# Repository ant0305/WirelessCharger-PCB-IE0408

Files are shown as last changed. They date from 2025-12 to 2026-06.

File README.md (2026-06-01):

# WirelessCharger-PCB-IE0408
Repositorio para el proyecto final del curso IE0408 sobre el diseño de una PCB de un cargador inalambrico. Contiene el circuito esquemático, el diseño de la PCB en *KiCad* y documentación sobre los componentes a utilizar, el procedimiento de diseño y otros detalles. 

Este repositorio y sus contenidos fueron diseñados durante el curso IE0408 durante el periodo II-2025 por los siguientes integrantes del equipo:

<div align="center">

| **Integrantes** | **Carné** | **Correo electrónico**|
|:---:|:---:|:---:|
| Anthony Calvo García | C11433  |  anthonycalvo50@gmail.com |
| Rodrigo Madrigal Montes | C24458  | rmadrigalmontes@gmail.com |

</div>

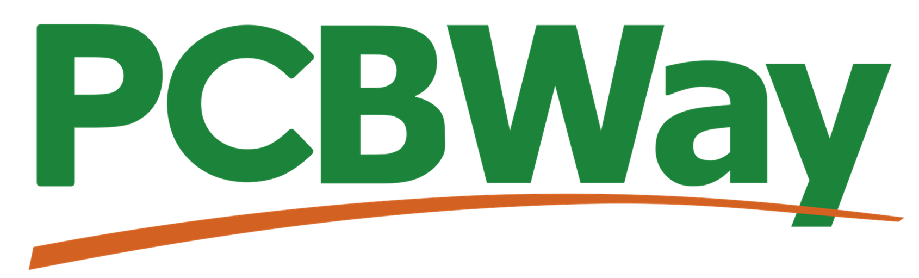
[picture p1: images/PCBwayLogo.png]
PCBWay_Logo
## Agradecimientos a  

El proyecto presentado fue posible gracias al valioso respaldo de **PCBWay**, a quienes deseamos extender nuestro más sincero agradecimiento. Las PCBs entregadas mostraron ser de una excelente calidad durante las pruebas realizadas, además de que el acabado en cada una de ellas es impecable, brindando exactamente el resultado que esperábamos.

Agradecemos, de igual manera, al equipo encargado de la atención al cliente, los cuales están siempre disponibles para brindar el apoyo solicitado de forma rápida y asertiva, lo que nos dio seguridad y tranquilidad durante todo el proceso de elaboración y entrega de las PCBs. 

### PCBs ensambladas 

Una vez recibidas las placas de PCBWay, se procedió con el ensamblaje manual de todos los componentes. A continuación se muestran imágenes del resultado:

<div align="center">

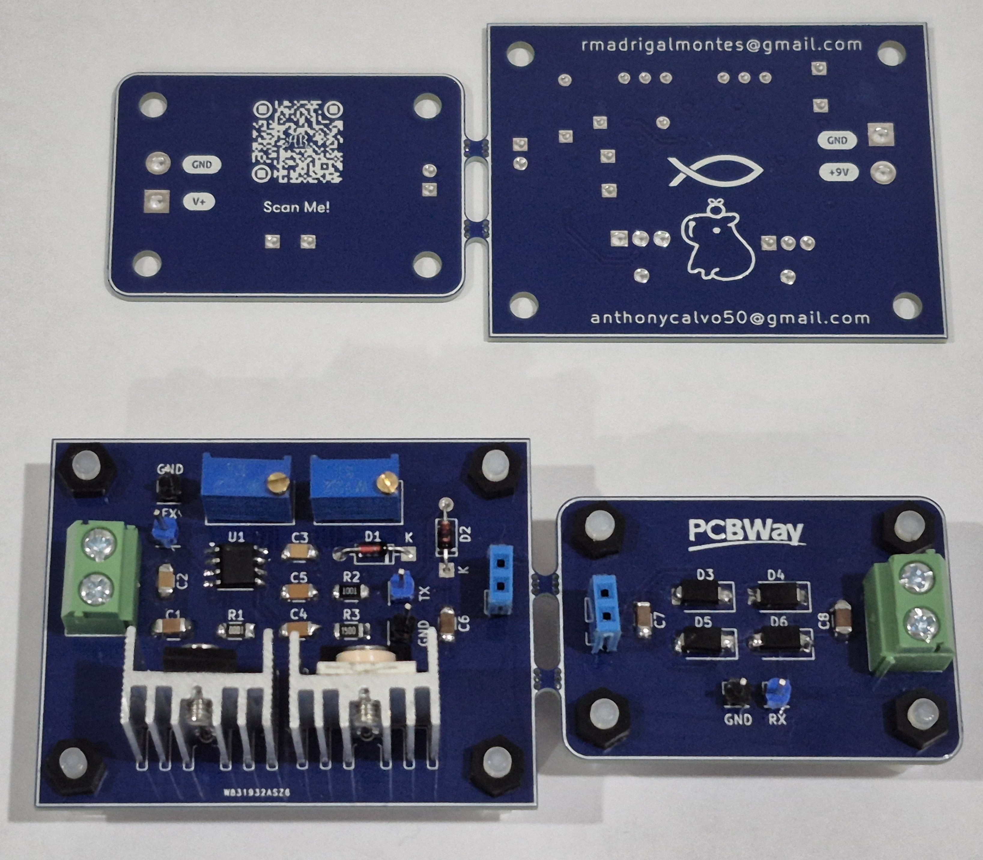
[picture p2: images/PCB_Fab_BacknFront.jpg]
PCBs_Fab_Unidas
|  |
|:-----------------------------:|
|    *PCBs ensambladas y no ensambladas aún unidas*     |

</div>

<div align="center">

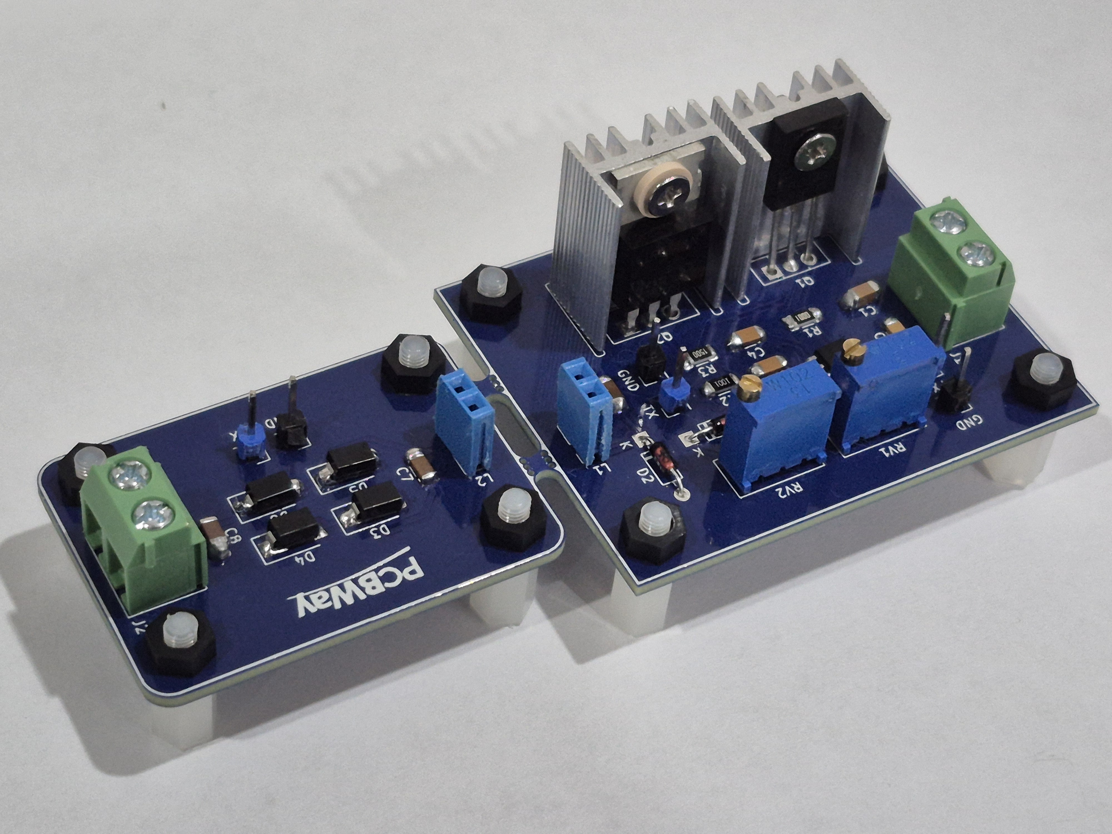
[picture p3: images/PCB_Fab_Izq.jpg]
PCBs_Fab_Izq
|  |
|:-----------------------------:|
|    *Vista lateral de las PCBs ensambladas unidas*     |

</div>

Una vez soldados todos los componentes en ambas PCBs se procedió a separarlas, rompiendo la uniones entre ambas como se muestra a continuación:

<div align="center">

| PCBs_Sep |
|:-----------------------------:|
|    *Separación de ambas PCBs*     |

</div>

Y una vez separadas, lijando el sobrante de la junta de unión en ambas PCBs y agregando las bobinas el resultado final es el siguiente:

<div align="center">

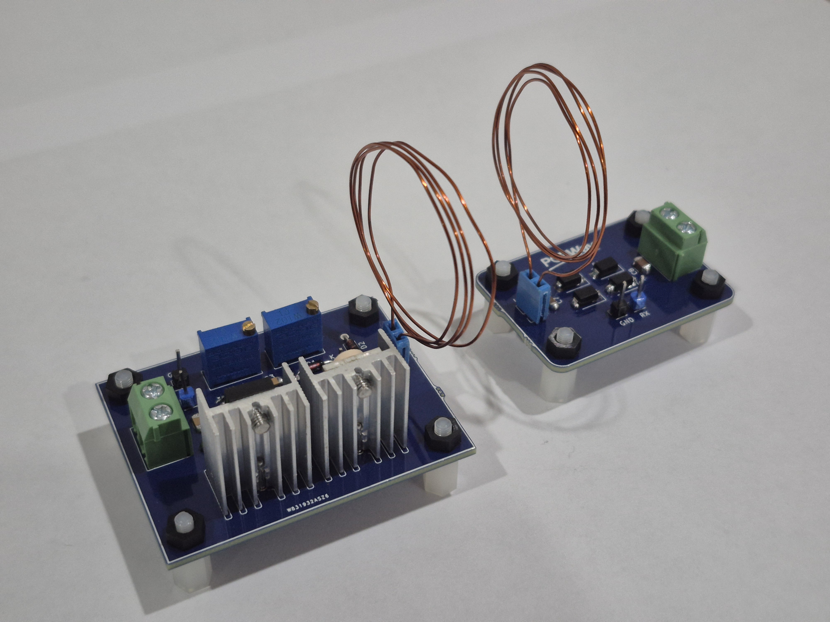
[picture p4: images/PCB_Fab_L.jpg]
PCBs_Fab_L
|  |
|:-----------------------------:|
|    *Ambas PCBs ensambladas y separadas*     |

</div>

Nuevamente extendemos nuestros agradecimientos a **PCBWay** por apoyar a la realización de este proyecto. Recomendamos sus servicios para estudiantes, profesionales y cualquier persona interesada en manufacturar PCBs de alta calidad. Más información en [pcbway.com](https://www.pcbway.com).

### Lista de componentes

A continuación se incluye una lista con los componentes utilizados en el diseño, con el mismo número que se les asignó en el diseño final de PCB:

<div align="center">

| Componente | Valor / Modelo | Descripción / Función | Encapsulado |
|:---:|:---:|:---:|:---:|
| C1, C8 | 10uF, 2.2uF | Capacitor cerámico | (SMD) 1206 |
| C2, C3 | 100nF | Capacitor cerámico | (SMD) 1206 |
| C4, C5 | 10nF | Capacitor cerámico | (SMD) 1206 |
| C6, C7 | 2nF | Capacitor cerámico | (SMD) 1206 |
| D1, D2 | 1N4148 | Diodo Rectificador de alta velocidad | (THT) DO-35 |
| D3, D4, D5, D6 | SS14 | Diodo Schottky | (SMD) DO-214|
| J1, J2 | — | Terminal de tornillo (2 pines) | — | 
| L1, L2 | 1x02 (2.54mm) Female Header | Conectores para colocar las bobinas | — |
| Q1 | BD139 | Transistor NPN de potencia | (THT) TO-126 |
| Q2 | IRFZ44N | Transistor MOSFET de potencia | (THT) TO-220 |
| R1 | 100Ω | Resistor | (SMD) 1206 |
| R3 | 150Ω | Resistor | (SMD) 1206 |
| R2| 1kΩ | Resistor | (SMD) 1206 |
| RV1, RV2 | 1kΩ | Resistor variable/Potenciómetro, | (THT) 3296W |
| U1 | NE555D | Circuito Integrado Temporizador NE555 | (SMD) SOP8 |
| TP1, TP3, TP6 | 1x01 (2.54mm) Pin Header | Punto de prueba (Test Point) para Tierra (GND) | — |
| TP2 | 1x01 (2.54mm) Pin Header | Punto de prueba (Test Point) para medir la Salida del NE555 | — | 
| TP4 | 1x01 (2.54mm) Pin Header | Punto de prueba (Test Point) para medir la tensión del Receptor (RX) | — |
| TP5 | 1x01 (2.54mm) Pin Header | Punto de prueba (Test Point) para medir la tensión del Receptor (TX) | — | 

</div>

## Diseño de la PCB

Una vez simulado y definido el circuito final, se diseñó la PCB en *KiCad* con una arquitectura de **cuatro capas**, las cuales se distribuyen de la siguiente manera:

- **F.Cu**: Ruta de señales
- **In1.Cu**: Plano de alimentación +9V
- **In2.Cu**: Plano de tierra (GND)
- **B.Cu**: Ruta de señales

### Capas de la PCB

<div align="center">

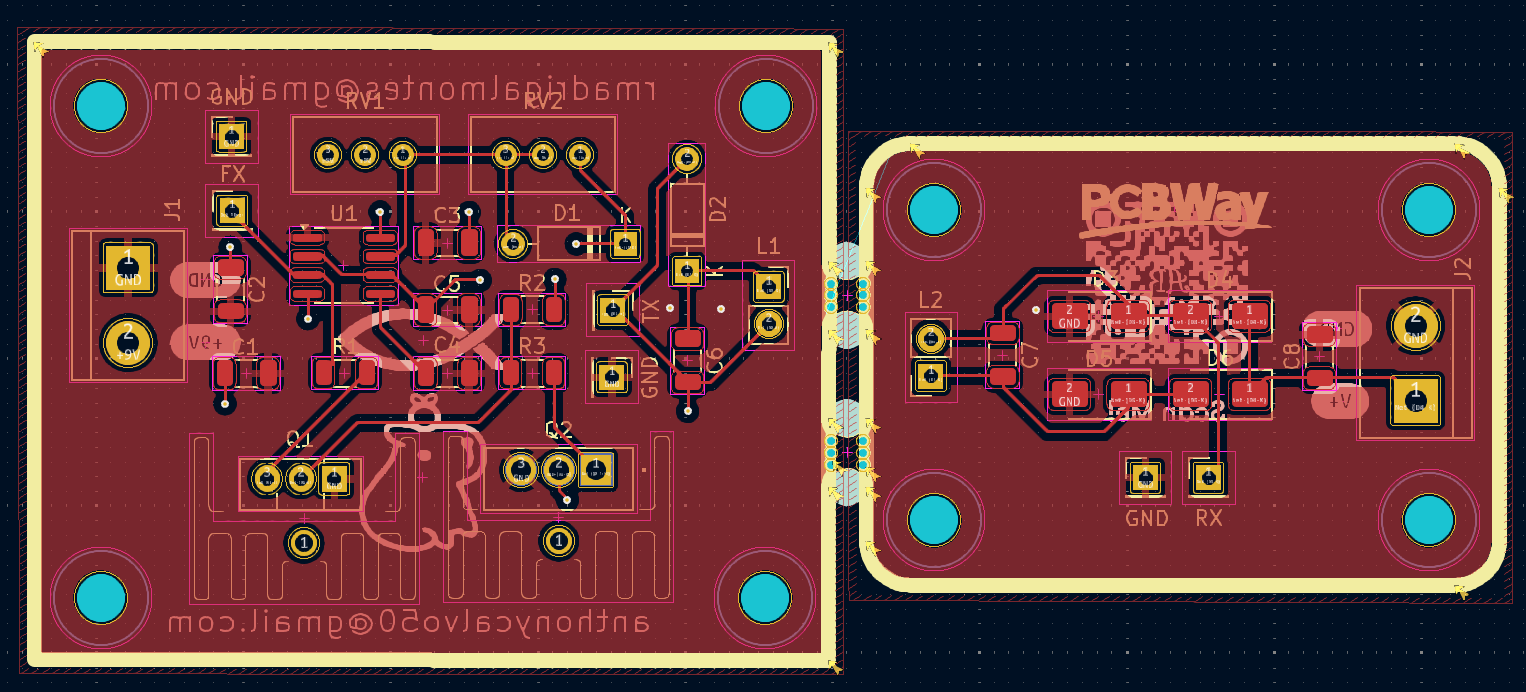
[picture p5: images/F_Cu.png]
Capa F.Cu
|  |
|:-----------------------------:|
|    *Capa superior (F.Cu)*     |

</div>

<div align="center">

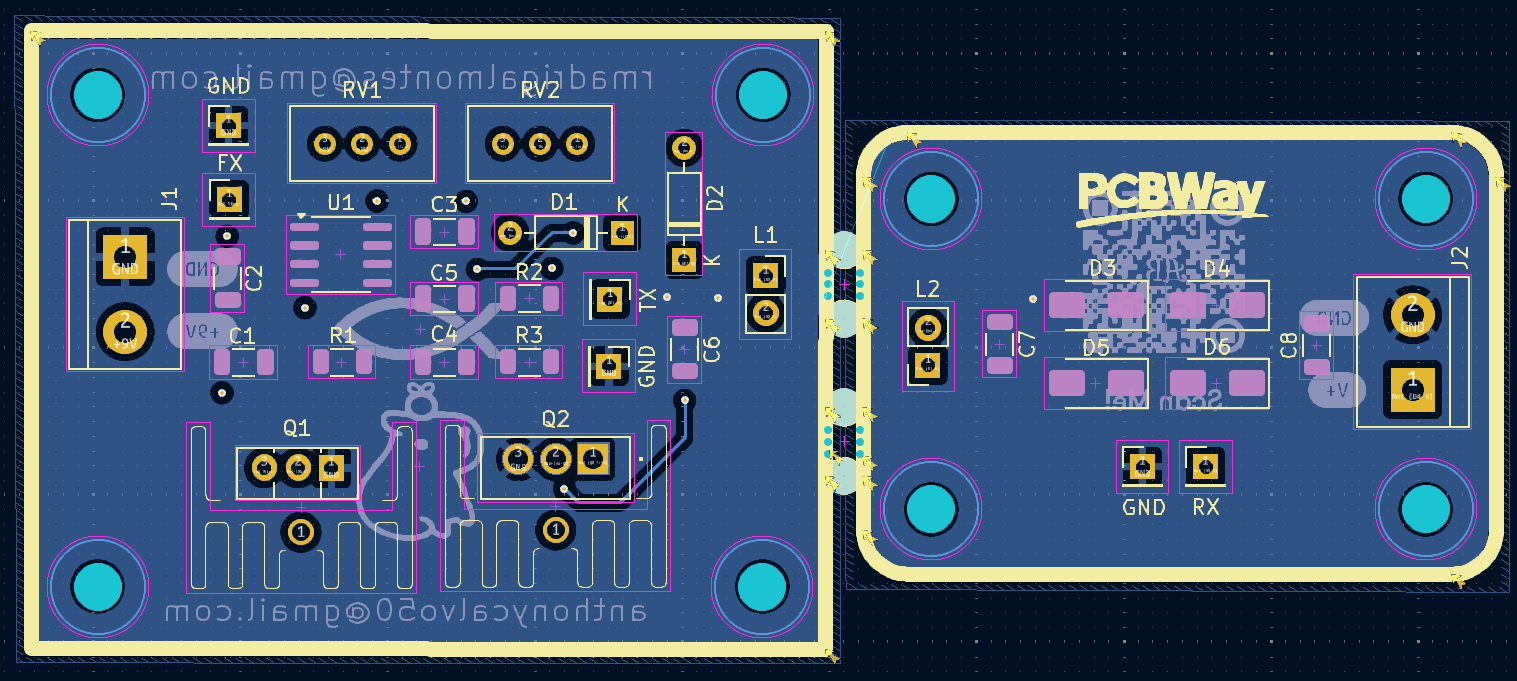
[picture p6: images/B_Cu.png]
Capa B.Cu
|  |
|:-----------------------------:|
|    *Capa inferior (B.Cu)*     |

</div>

<div align="center">

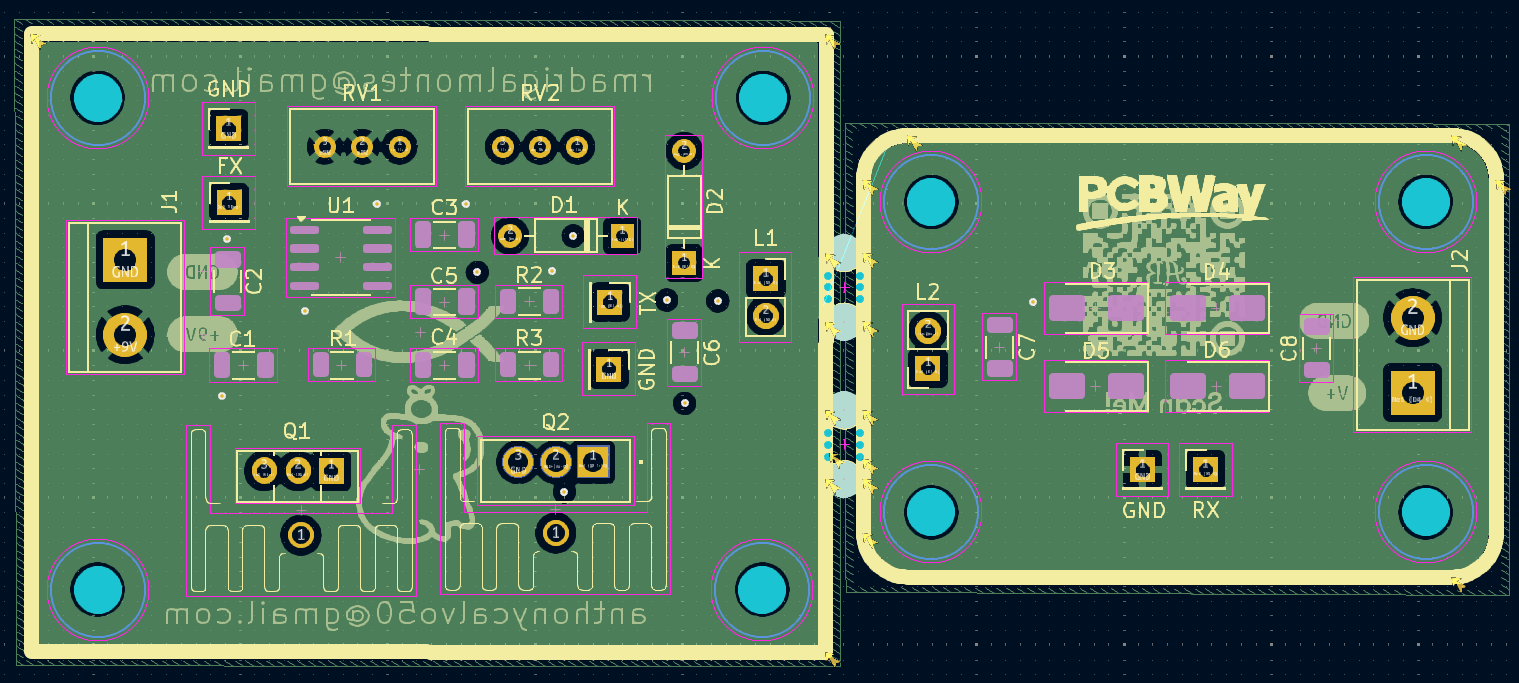
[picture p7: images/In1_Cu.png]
In1.Cu - Alimentación
|  |
|:-------------------------------------------:|
|      *Capa interna 1 (In1.Cu)- +9V*         |

</div>

<div align="center">

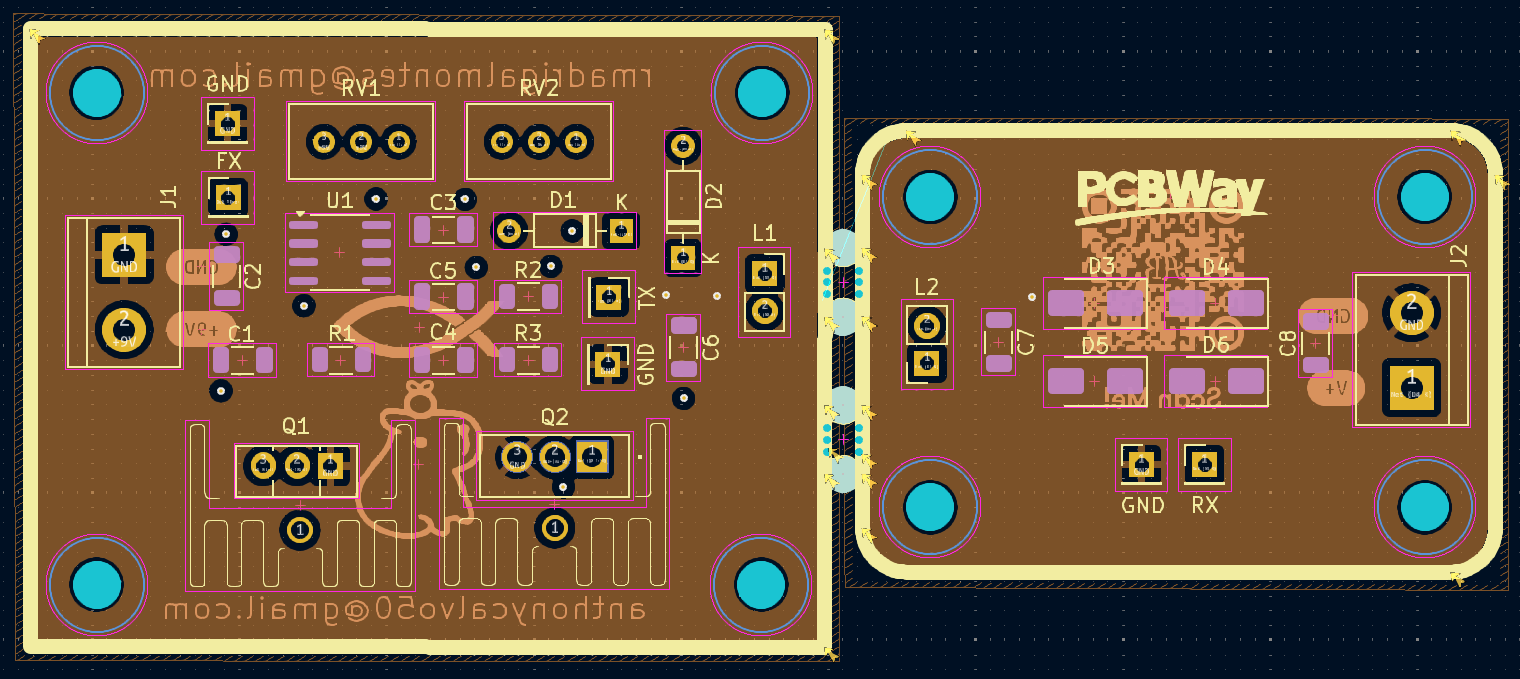
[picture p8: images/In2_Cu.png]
In2.Cu - Tierra
|  |
|:-------------------------------------:|
|        *Capa interna (In2.Cu) - GND*         |

</div>

Además, se agregaron zonas de serigrafía, agujeros de montaje, así como textos identificativos y logotipos en el *silkscreen* con el nombre del proyecto y los autores. Como resultado final se muestra la PCB en el visor 3D de *KiCad* con y sin los modelos 3D 

<div align="center">

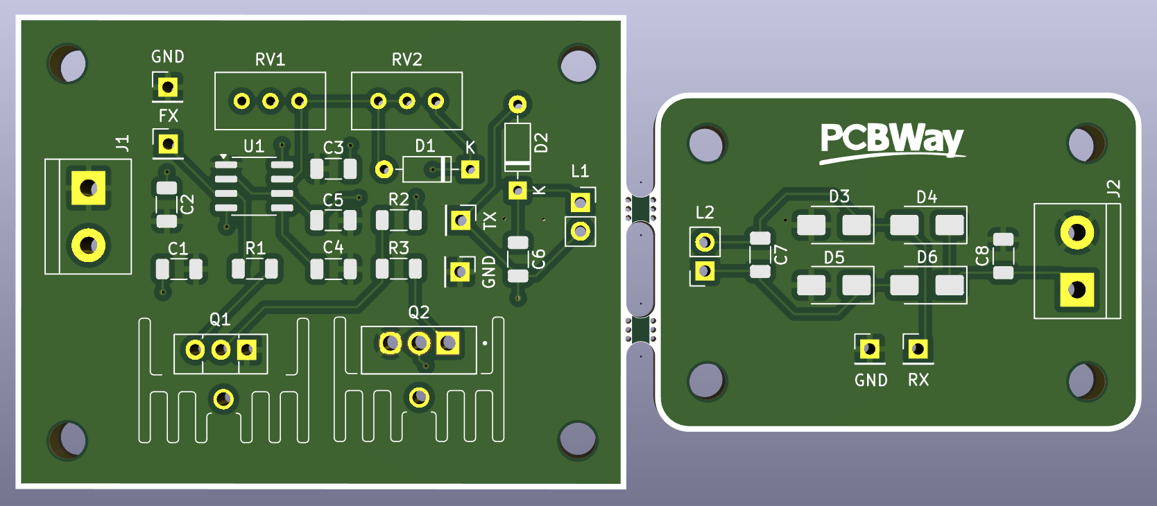
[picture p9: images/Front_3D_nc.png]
|  |
|:--:|
| *Vista 3D Frontal de la PCB en KiCad* |

</div>

<div align="center">

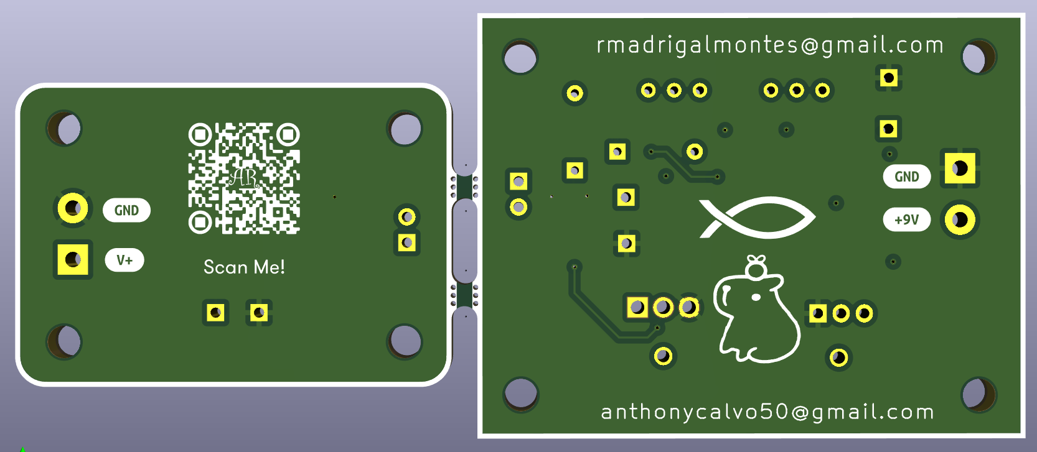
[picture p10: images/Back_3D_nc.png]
|  |
|:--:|
| *Vista 3D Frontal de la PCB en KiCad* |

</div>

<div align="center">

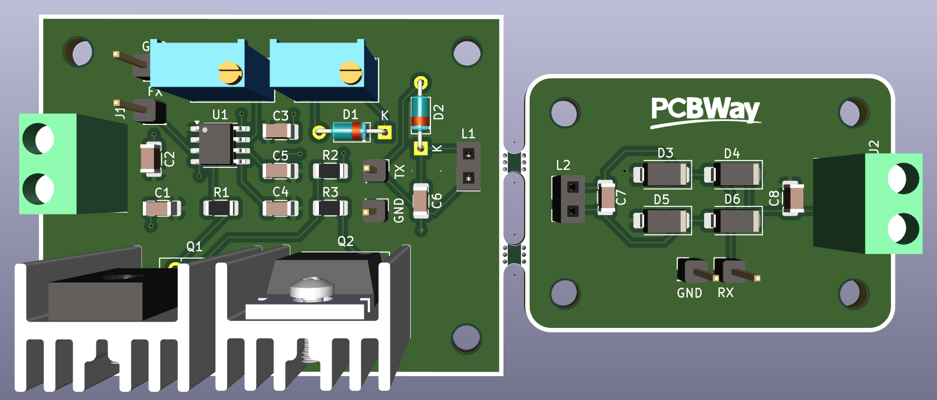
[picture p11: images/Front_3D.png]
Vista 3D Frontal de la PCB con Modelos
|  |
|:--:|
| *Vista 3D Frontal de la PCB en KiCad con modelos 3D* |

</div>

<div align="center">

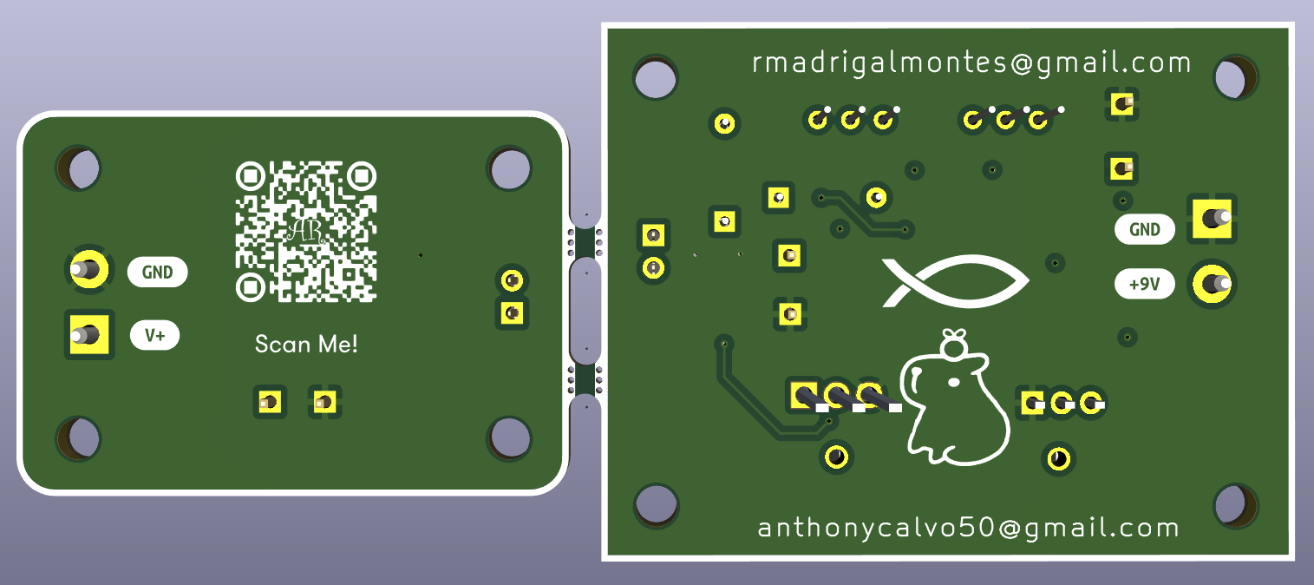
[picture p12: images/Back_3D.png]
Vista 3D Trasera de la PCB con Modelos
|  |
|:--:|
| *Vista 3D Trasera de la PCB en KiCad con modelos 3D* |

</div>

<div align="center">

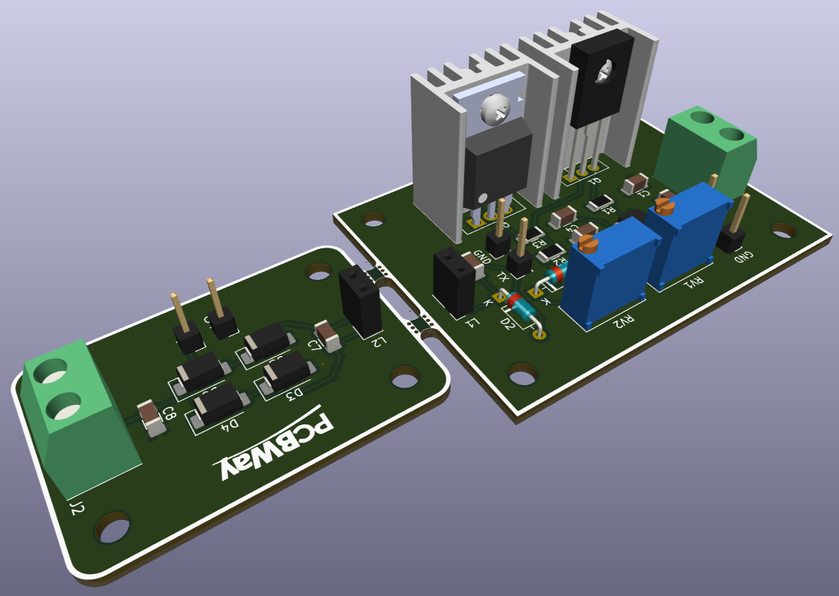
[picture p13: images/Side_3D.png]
Vista 3D Lateral Izquierda de la PCB con 3D
|  |
|:--:|
| *Vista 3D Lateral Izquierda de la PCB en KiCad con modelos 3D* |

</div>

## Diseño de una carcasa 3D

De forma adicional, se diseñó una carcasa 3D usando la herramienta FreeCAD que permite comprobar el correcto funcionamiento del prototipo y cómo cambia la cantidad de energía entregada dependiendo de la distancia entre el receptor y el emisor.

<div align="center">

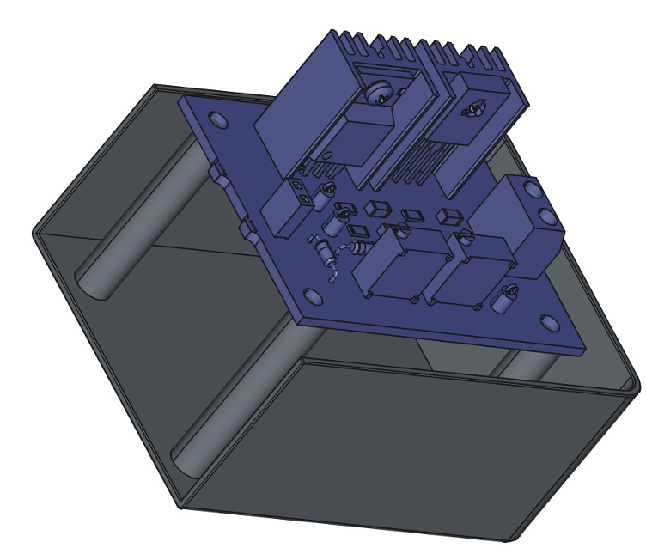
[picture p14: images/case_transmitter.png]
Vista 3D de la carcasa del emisor
|  |
|:--:|
| *Vista 3D de la carcasa diseñada para el emisor* |

</div>

<div align="center">

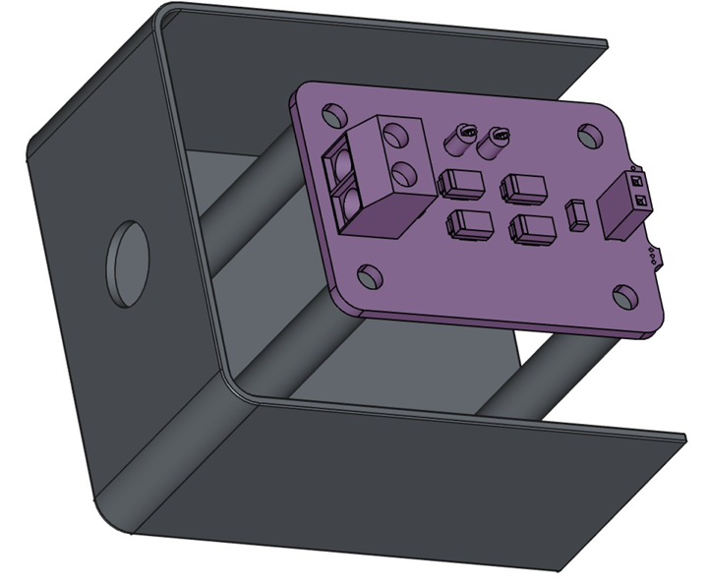
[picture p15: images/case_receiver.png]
Vista 3D de la carcasa del receptor
|  |
|:--:|
| *Vista 3D de la carcasa diseñada para el receptor* |

</div>

<div align="center">

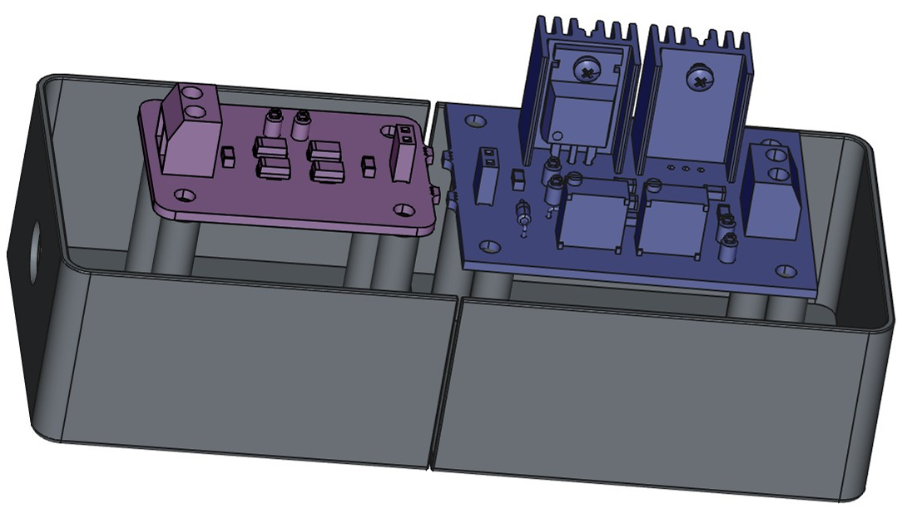
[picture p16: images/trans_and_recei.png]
Vista 3D de la carcasa del receptor y emisor
|  |
|:--:|
| *Unión del emisor y receptor usando la carcasa diseñada* |

</div>

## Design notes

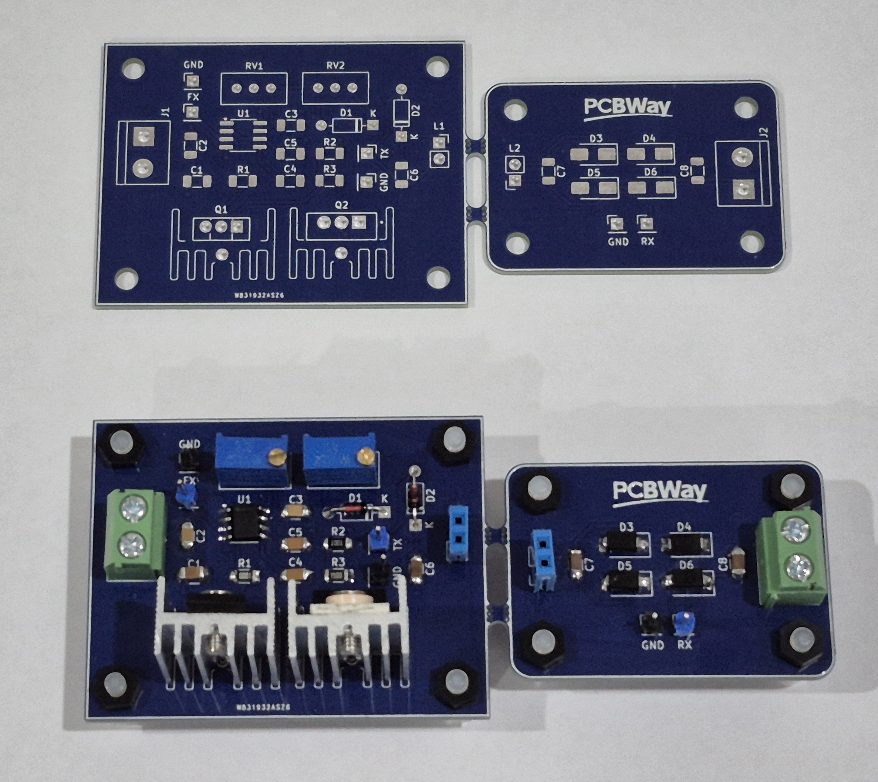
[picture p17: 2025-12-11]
images/PCB_F_NF.jpg

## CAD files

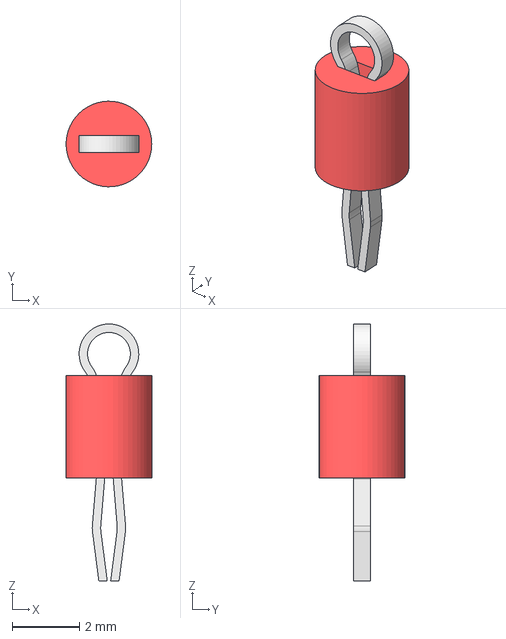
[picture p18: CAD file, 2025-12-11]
kicad_project/3Dmodels/TP_RED_1.0mm_miniature.stp
2.54 x 2.54 x 7.62 mm

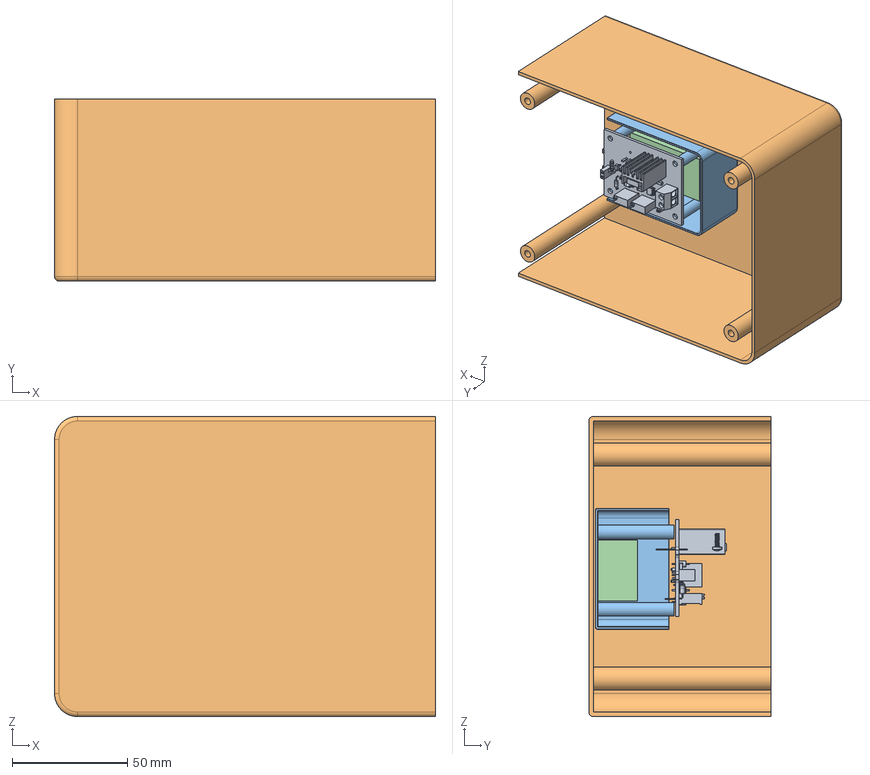
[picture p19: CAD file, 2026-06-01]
kicad_project/Freecad_case/emisor.FCStd
165.0 x 79.0 x 130.0 mm
Cuerpo
Caja

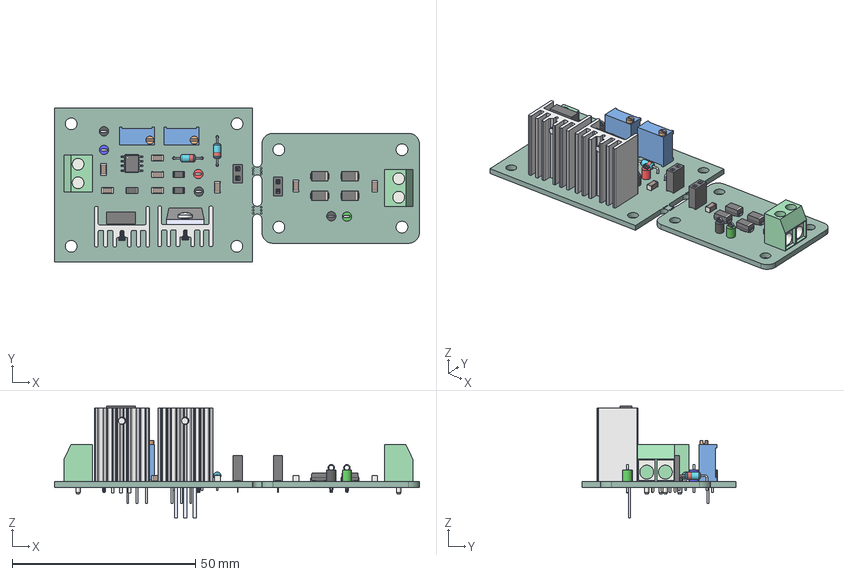
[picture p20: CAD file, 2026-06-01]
kicad_project/WirelessChargerPCB.step
99.5 x 42.0 x 30.5 mm
TerminalBlock_bornier-2_P5.08mm x 2
PinSocket_1x02_P254mm_Vertical x 2
R_1206_3216Metric x 3
C_1206_3216Metric x 8
D_DO-35_SOD27_P7.62mm_Horizontal x 2
D_SMA x 4
SOIC_8_39x49mm_P127mm
IRFZ44N
ASSEMBLY x 2
Potentiometer_Bourns_3296W_Vertical x 2
TO-126-3_Vertical
WirelessChargerPCB_PCB

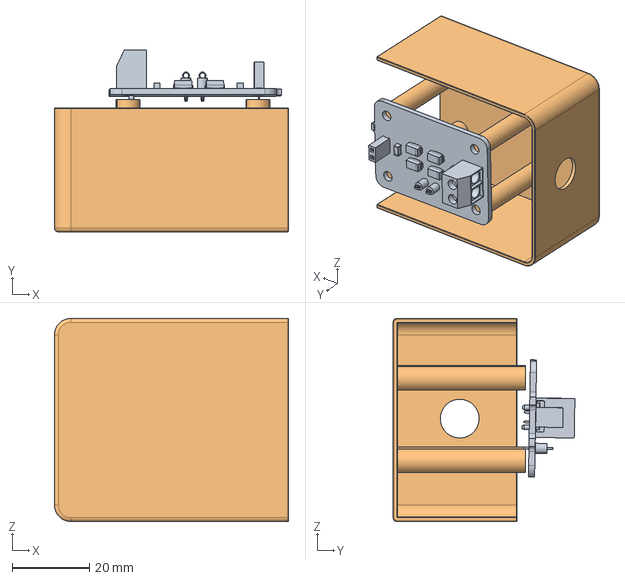
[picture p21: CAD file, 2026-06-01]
kicad_project/Freecad_case/receptor.FCStd
60.4 x 46.9 x 52.4 mm
Slice003.0

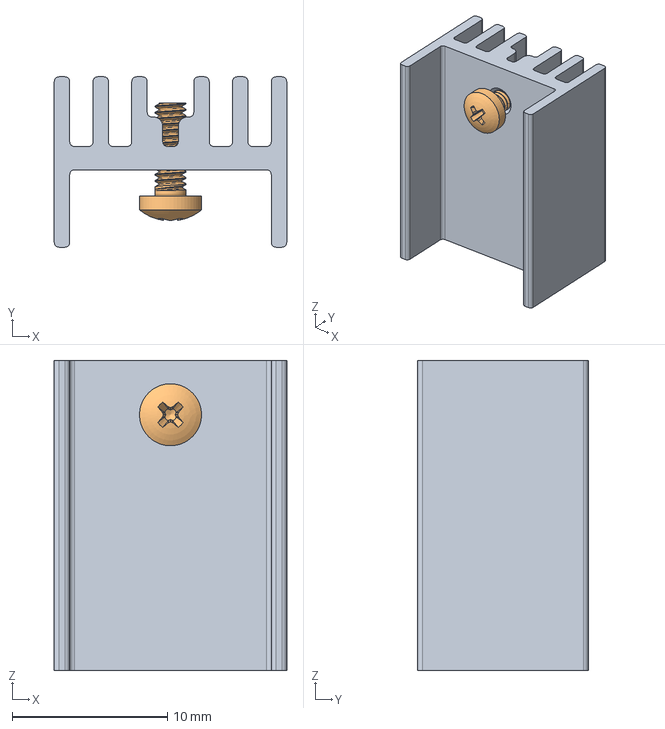
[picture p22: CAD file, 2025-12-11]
kicad_project/3Dmodels/HeatsinkTO220.step
15.0 x 11.0 x 20.0 mm
HeatSink
M2x6-Screw

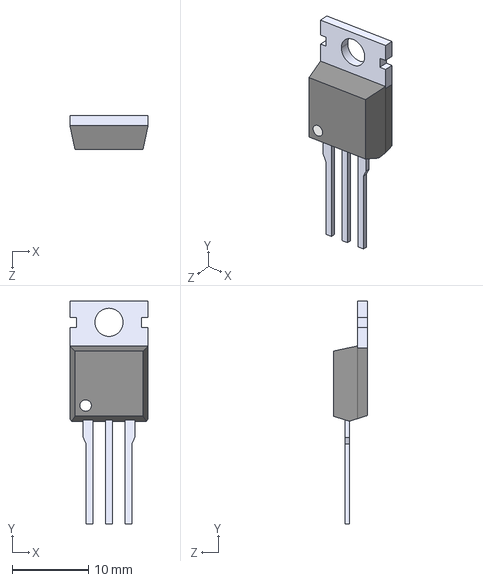
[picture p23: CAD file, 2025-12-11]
kicad_project/3Dmodels/IRFZ44N.step
10.3 x 29.3 x 4.50 mm

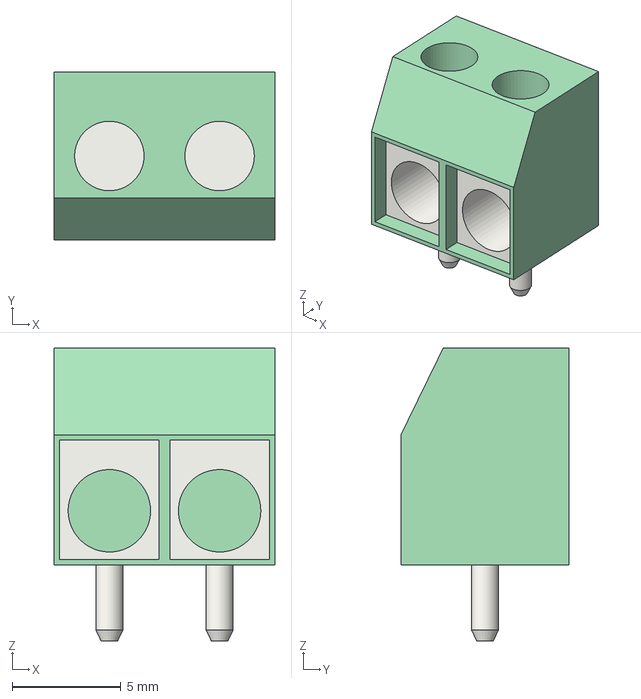
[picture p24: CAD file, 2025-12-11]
kicad_project/3Dmodels/TerminalBlock_bornier-2_P5.08mm.step
10.2 x 7.75 x 13.5 mm

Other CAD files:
kicad_project/3Dmodels/TP_GREEN_1.0mm_miniature.stp
kicad_project/3Dmodels/TP_BLACK_1.0mm_miniature.stp
kicad_project/3Dmodels/TP_BLUE_1.0mm_miniature.stp

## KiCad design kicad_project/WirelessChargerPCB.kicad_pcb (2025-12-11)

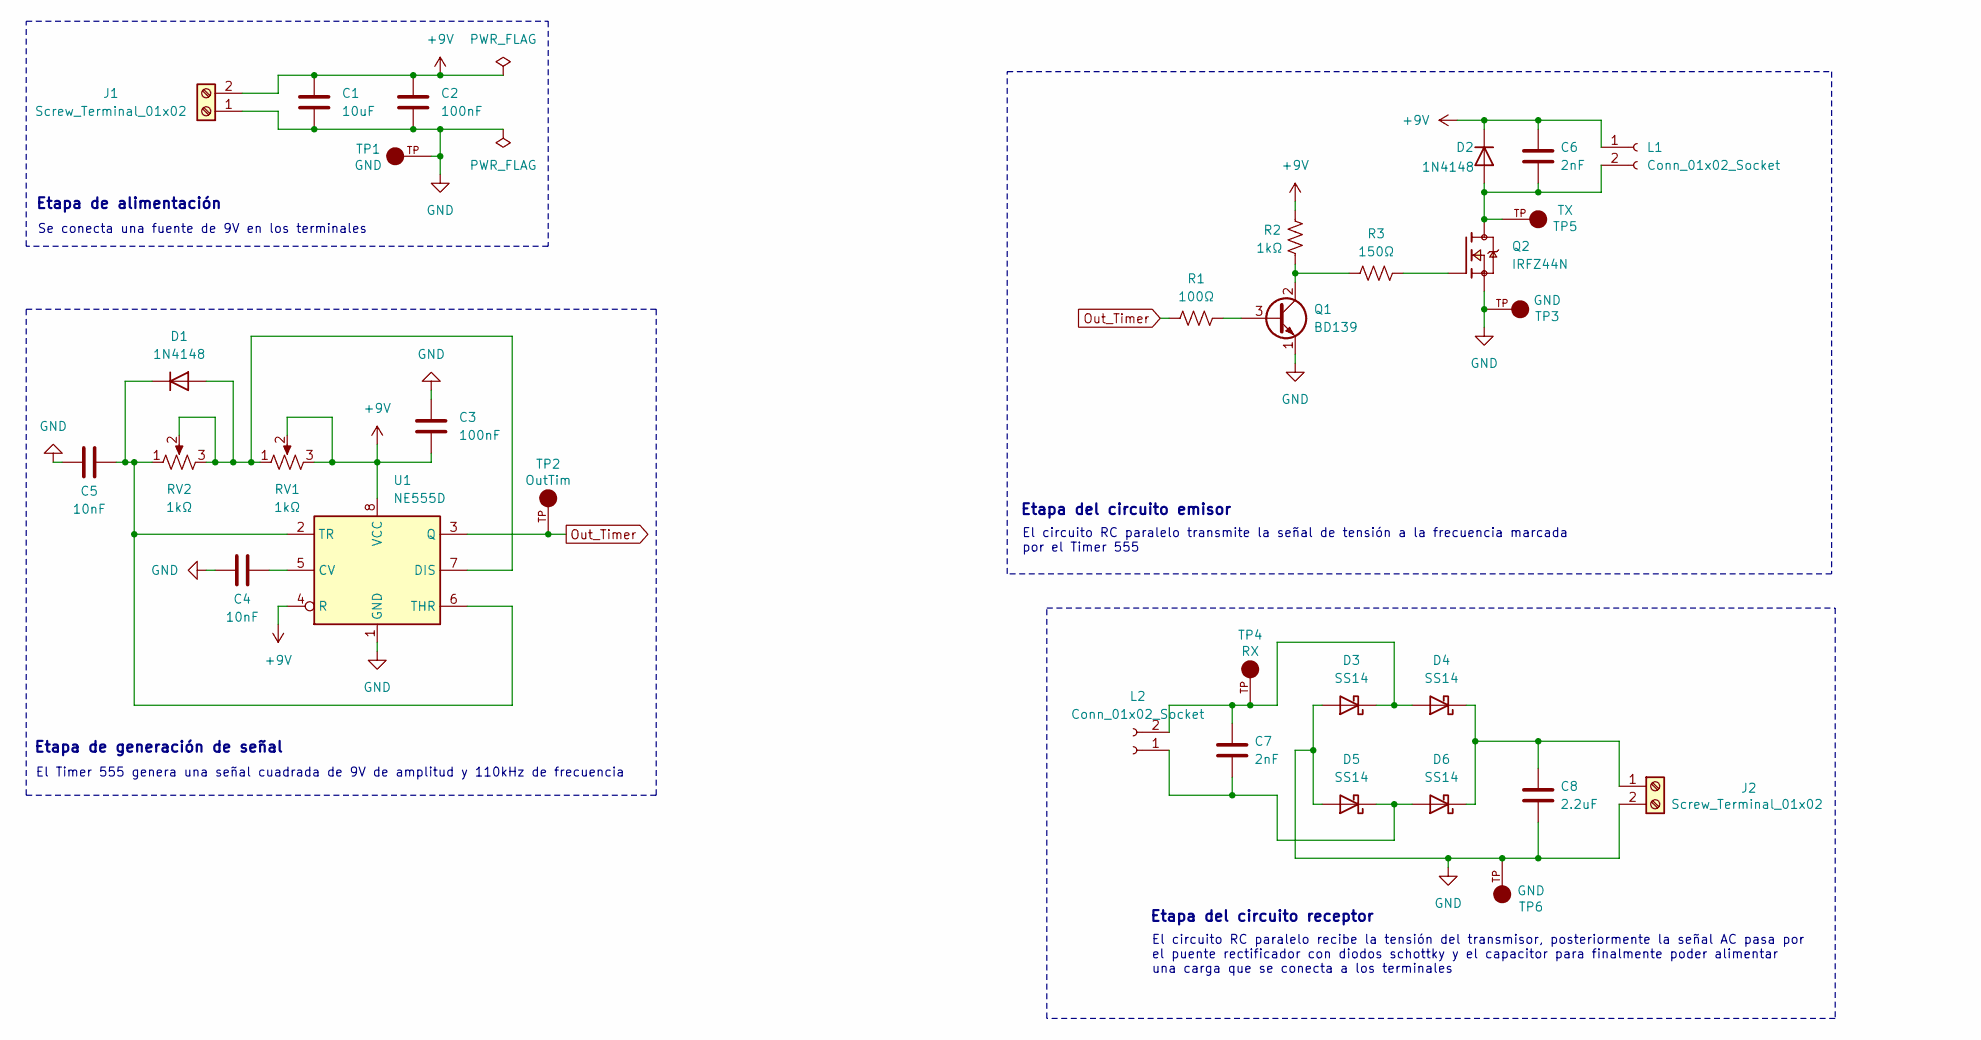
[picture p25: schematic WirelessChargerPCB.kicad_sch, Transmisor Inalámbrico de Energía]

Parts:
C1: 10uF; C_1206_3216Metric
C2, C3: 100nF; C_1206_3216Metric
C4, C5: 10nF; C_1206_3216Metric
C6, C7: 2nF; C_1206_3216Metric
C8: 2.2uF; C_1206_3216Metric
D1, D2: 1N4148; D_DO-35_SOD27_P7.62mm_Horizontal
D3, D4, D5, D6: SS14; D_SMA
J1, J2: Screw_Terminal_01x02; TerminalBlock_bornier-2_P5.08mm
L1, L2: Conn_01x02_Socket; PinSocket_1x02_P2.54mm_Vertical
Q1: BD139; TO-126-3_Vertical
Q2: IRFZ44N; TO254P1016X419X2286-3; PARTREV 09/21/10
R1: 100Ω; R_1206_3216Metric
R2: 1kΩ; R_1206_3216Metric
R3: 150Ω; R_1206_3216Metric
RV1, RV2: 1kΩ; Potentiometer_Bourns_3296W_Vertical
TP1, TP3, TP6: GND; KEYSTONE_5263; PARTREV H
TP2: OutTim; KEYSTONE_5263; PARTREV H
TP4: RX; KEYSTONE_5263; PARTREV H
TP5: TX; KEYSTONE_5263; PARTREV H
U1: NE555D; SOIC-8_3.9x4.9mm_P1.27mm

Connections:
+9V: C1.1, C2.1, C3.2, C6.1, D2.1 (K), J1.2, L1.1, R2.2, RV1.2, RV1.3, U1.4 (R), U1.8 (VCC)
GND: C1.2, C2.2, C3.1, C4.1, C5.1, C8.2, D3.2 (A), D5.2 (A), J1.1, J2.2, Q1.1 (E), Q2.3, TP1.TP, TP3.TP, TP6.TP, U1.1 (GND)
unnamed: D1.2 (A), RV1.1, RV2.2, RV2.3, U1.7 (DIS)
unnamed: C5.2, D1.1 (K), RV2.1, U1.2 (TR), U1.6 (THR)
unnamed: C6.2, D2.2 (A), L1.2, Q2.2, TP5.TP
unnamed: C7.1, D3.1 (K), D4.2 (A), L2.2, TP4.TP
unnamed: C8.1, D4.1 (K), D6.1 (K), J2.1
unnamed: C7.2, D5.1 (K), D6.2 (A), L2.1
unnamed: Q1.3 (B), R1.2
unnamed: Q1.2 (C), R2.1, R3.1
unnamed: Q2.1, R3.2
unnamed: C4.2, U1.5 (CV)
Out_Timer: R1.1, TP2.TP, U1.3 (Q)

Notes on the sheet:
El Timer 555 genera una señal cuadrada de 9V de amplitud y 110kHz de frecuencia
Etapa de generación de señal
Etapa del circuito emisor
Etapa de alimentación
El circuito RC paralelo recibe la tensión del transmisor, posteriormente la señal AC pasa por el puente rectificador con diodos schottky y el capacitor para finalmente poder alimentar una carga que se conecta a los terminales
El circuito RC paralelo transmite la señal de tensión a la frecuencia marcada por el Timer 555
Se conecta una fuente de 9V en los terminales
Etapa del circuito receptor

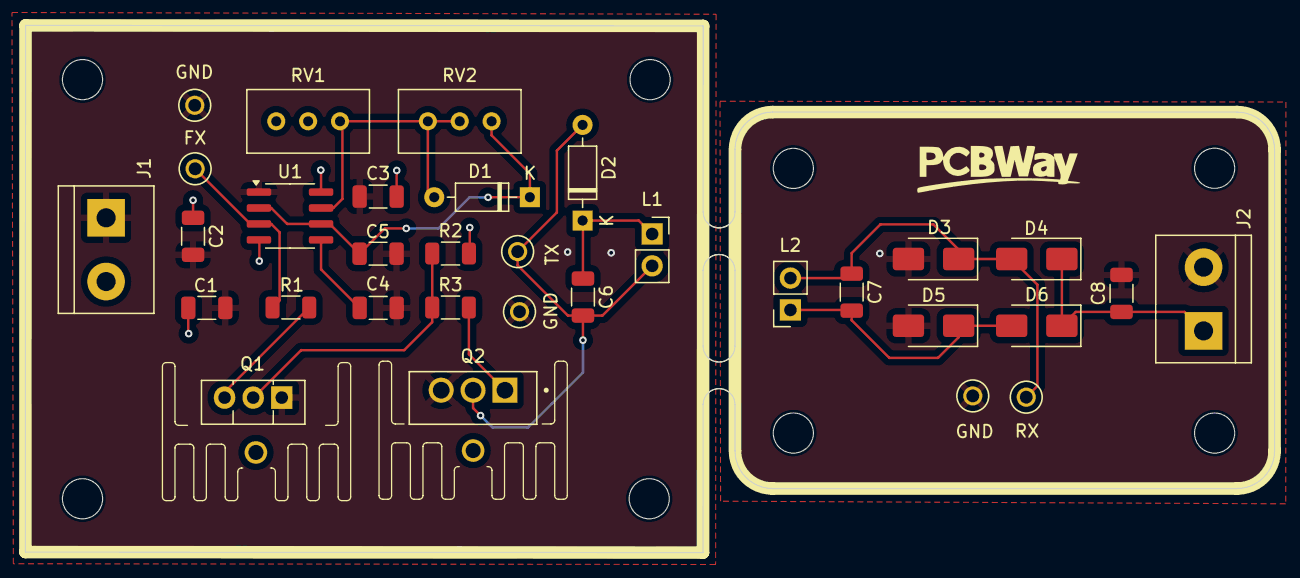
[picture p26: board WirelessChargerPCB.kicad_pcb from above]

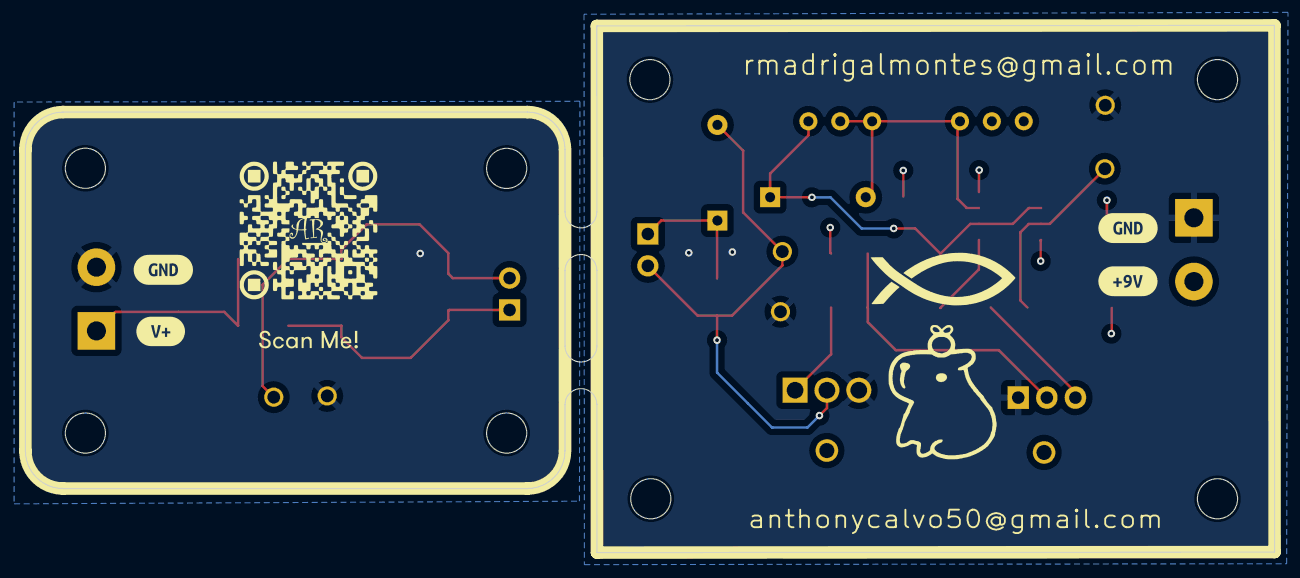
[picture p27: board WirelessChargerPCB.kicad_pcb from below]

Board: 4 copper layers, 99.5 x 42.0 mm, 38 parts (4 on the bottom side), 13 nets.

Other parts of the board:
kibuzzard-69159BA1: G***; kibuzzard-69159BA1
kibuzzard-69159BFD: G***; kibuzzard-69159BFD
kibuzzard-69159C7D: G***; kibuzzard-69159C7D
kibuzzard-69159C9A: G***; kibuzzard-69159C9A
mouse-bite-2.54mm-slot, mouse-bite-2.54mm-slot#2: VAL**; mouse-bite-2.54mm-slot

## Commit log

2025-11-06 Agregando archivos del proyecto de la PCB en KiCad
    [TerminalBlock_bornier-2_P5.08mm.step, WirelessChargerPCB.kicad_pcb, WirelessChargerPCB.kicad_sch]
2025-11-06 Agregando nombre de los integrantes al README.md
2025-11-12 Agregando huellas y modelos 3D, además de otros cambios en el editor de placas y esquemático
    [HeatsinkTO220.step, IRFZ44N.step, WirelessChargerPCB.kicad_pcb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]
2025-11-13 Agregando huellas de Heatsinks y relizando acomodo de ambas PCBs
    [WirelessChargerPCB.kicad_pcb, WirelessChargerPCB.kicad_sch]
2025-11-13 Ruteando y agregando detalles en Silkscreen en ambas PCBs
    [WirelessChargerPCB.kicad_pcb]
2025-11-15 Agregando informacion importante al silkcreem ademas del agujero de montaje para el disipador asi como una reconfiguracion a la placa del circuito transmisor
    [WirelessChargerPCB.kicad_pcb]
2025-11-15 Agregando mouse-bites y logos en ambas PCBs
    [WirelessChargerPCB.kicad_pcb]
2025-11-15 Agregando imagenes de la PCB en KiCad
2025-11-15 Recortando imagenes de las vistas 3D de las PCBs
2025-11-15 Agregando archivos de fabricacion en el directorio outputs/
    [WirelessChargerPCB-B_Cu.gbr, WirelessChargerPCB-B_Mask.gbr, WirelessChargerPCB-B_Paste.gbr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]
2025-11-19 Agregando una conexion faltante en el esquematico y actualizando el editor de placas
    [WirelessChargerPCB.kicad_sch]
2025-12-03 Agregando nuevos puntos de prueba y corrigiendo +9V faltante
    [TP_BLACK_1.0mm_miniature.stp, TP_BLUE_1.0mm_miniature.stp, TP_GREEN_1.0mm_miniature.stp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]
2025-12-03 Agregando nuevos archivos de fabricacion
    [WirelessChargerPCB-B_Cu.gbr, WirelessChargerPCB-B_Mask.gbr, WirelessChargerPCB-B_Paste.gbr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]
2025-12-06 Agregando parte de la documentacion del proyecto
2025-12-07 Corrigiendo un error en la ultima imagen
2025-12-10 Agregando sección de agradecimientos a PCBWay en el README.md
2025-12-10 Agregando imagen del logo de PCBWay en el README.md
2025-12-10 Ajustando logo de PCBWay en el README.md
    Ajustando logo de PCBWay en el README.md
2026-06-01 Agregando la documentación respecto a la implementación 3D diseñada
    [WirelessChargerPCB.step]
2026-06-01 Agregando los archivos de fabricación de la implementación 3D diseñada
    [emisor.FCStd, receptor.FCStd]
